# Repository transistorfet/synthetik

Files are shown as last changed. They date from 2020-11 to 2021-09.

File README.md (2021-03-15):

Synthetik
=========

###### *Started October 21, 2020*

This project started after I bought some old sound synthesis chips that were commonly used in
video game consoles and computers from the 80s and early 90s.  The first revision is a shield
for an Arduino Mega with 4 different chips: the General Instruments AY-3-8910 / Yamaha YM2149,
the YM2612 / YM3438 (OPN), the YM3812 (OPL2), and the YMF262 (OPL3).  It also has a MIDI in
port, line out stereo jack, and a headphone stereo jack with a TDA1308 power amplifier.

The board design had a large number of issues and mistakes, and I've so far only got it working
with one chip.

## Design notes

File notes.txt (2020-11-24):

Starting TTY Midi Bridge:

cd /media/work/Reference/Arduino/ttymidi
./ttymidi -s /dev/ttyACM2 -v

Connect VMPK to tty:

aconnect 130:0 128:1

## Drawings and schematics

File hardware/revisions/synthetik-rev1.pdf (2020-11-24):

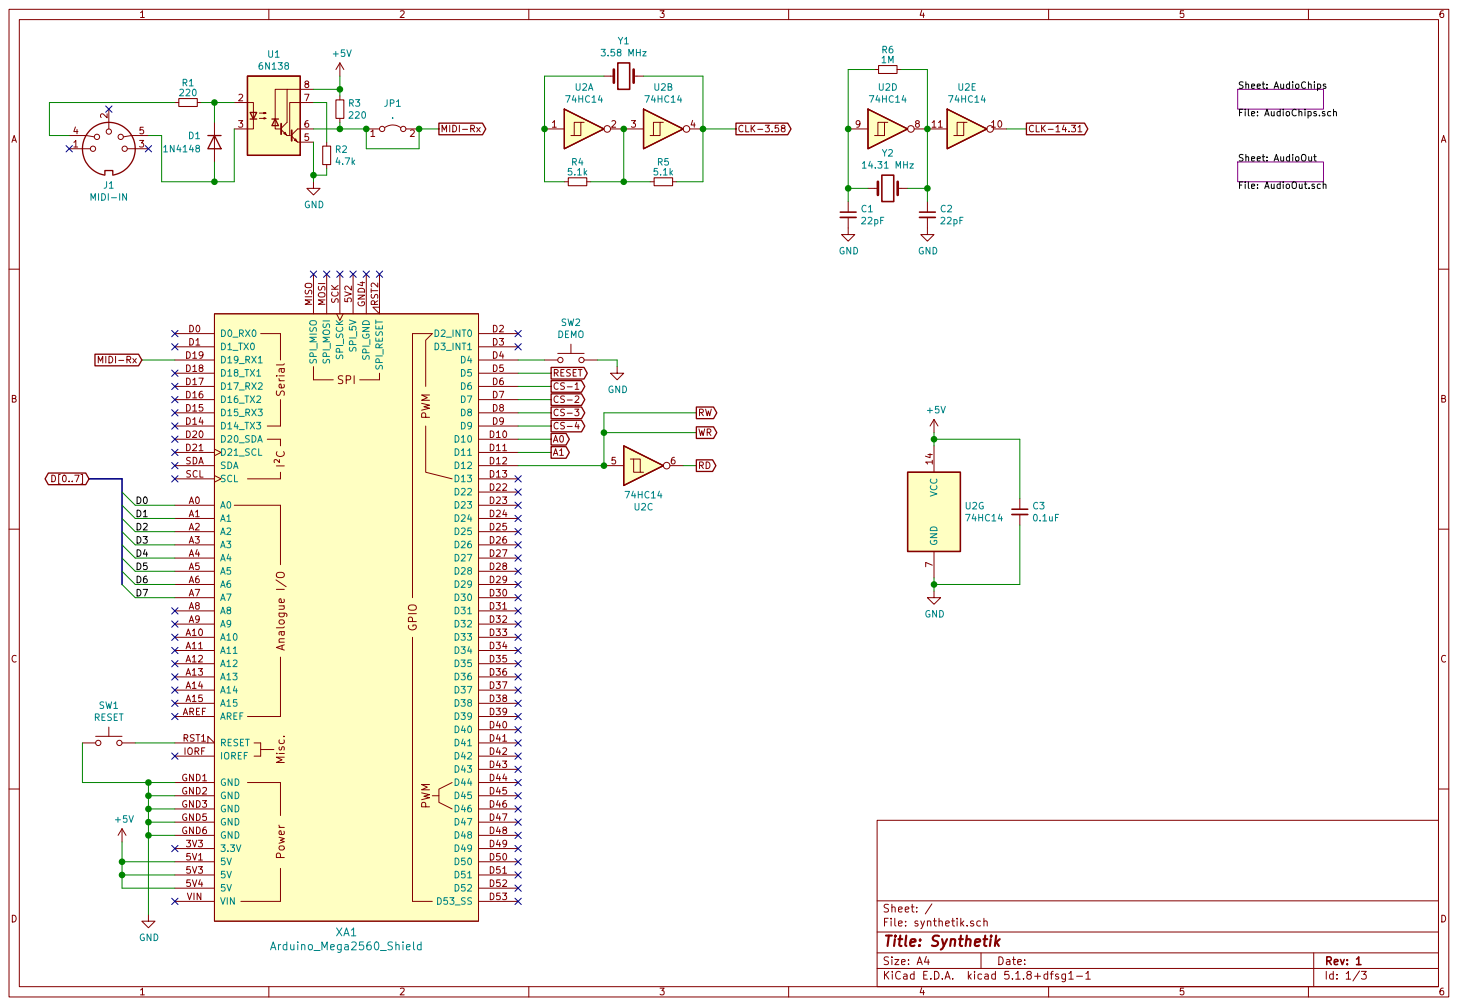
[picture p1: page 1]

Sheet: AudioOut File: AudioOut.sch Sheet: AudioChips

File: synthetik.sch Sheet: /
Id: 1/3 Title: Synthetik

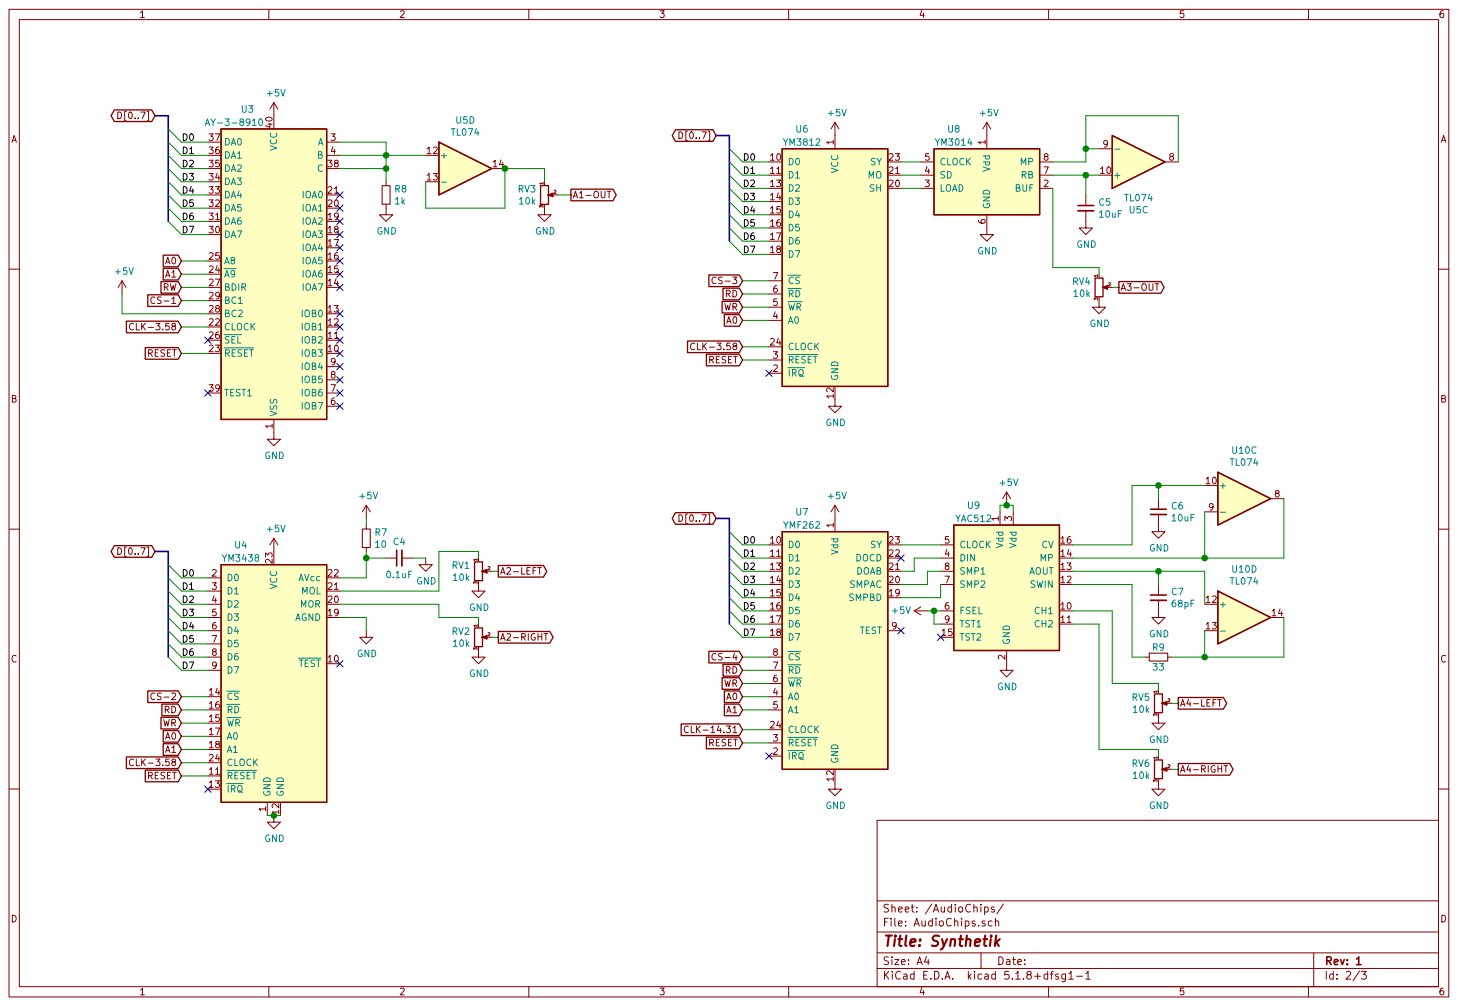
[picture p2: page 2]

A3-OUT D[0..7] CLK-3.58 RESET WR

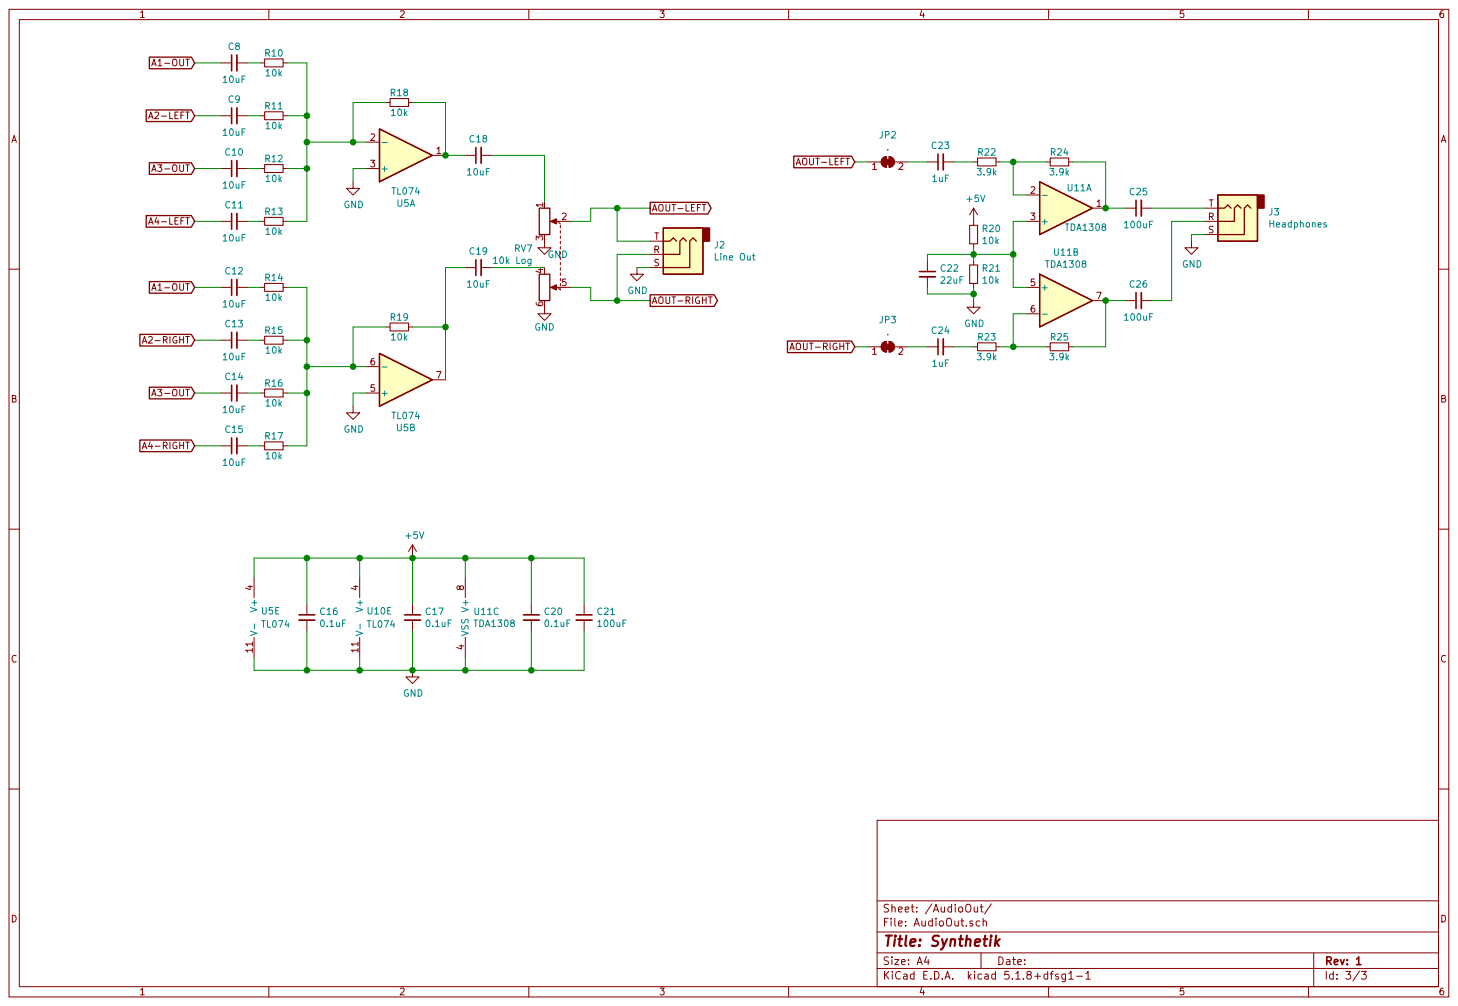
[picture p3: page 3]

File: AudioOut.sch Sheet: /AudioOut/
Id: 3/3 Title: Synthetik

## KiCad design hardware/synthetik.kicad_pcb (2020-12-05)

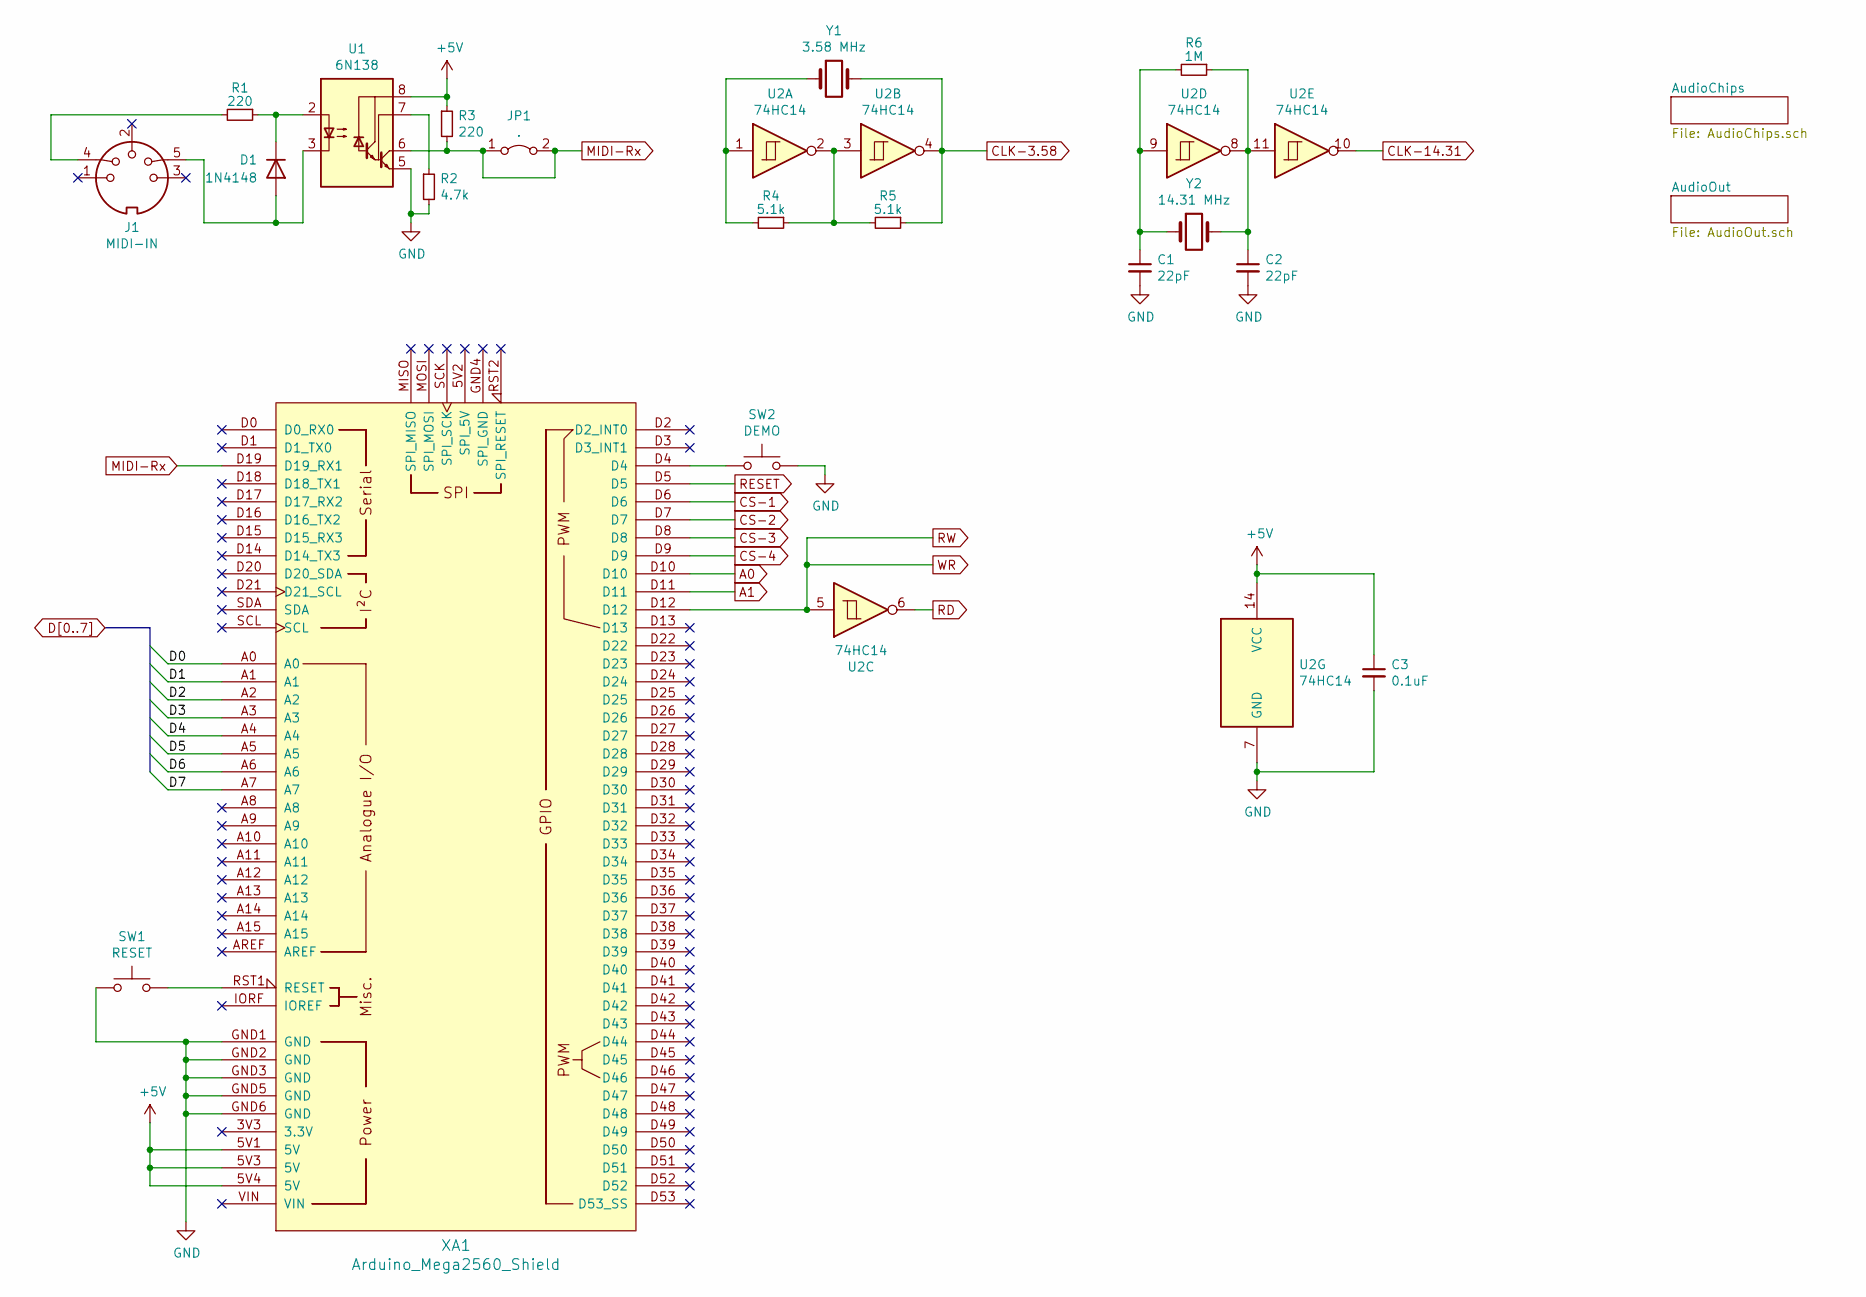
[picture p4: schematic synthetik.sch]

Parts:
C1, C2: 22pF; C_Disc_D3.0mm_W2.0mm_P2.50mm
C3: 0.1uF; C_Disc_D3.0mm_W2.0mm_P2.50mm
D1: 1N4148; D_DO-35_SOD27_P7.62mm_Horizontal
J1: MIDI-IN; MIDI_DIN5
JP1: .; PinHeader_1x02_P2.54mm_Vertical
R1, R3: 220; R_Axial_DIN0207_L6.3mm_D2.5mm_P7.62mm_Horizontal
R2: 4.7k; R_Axial_DIN0207_L6.3mm_D2.5mm_P7.62mm_Horizontal
R4, R5: 5.1k; R_Axial_DIN0207_L6.3mm_D2.5mm_P7.62mm_Horizontal
R6: 1M; R_Axial_DIN0207_L6.3mm_D2.5mm_P7.62mm_Horizontal
SW1: RESET; SW_PUSH_6mm
SW2: DEMO; SW_PUSH_6mm
U1: 6N138; DIP-8_W7.62mm_LongPads
U2: 74HC14; DIP-14_W7.62mm_Socket_LongPads
XA1: Arduino_Mega2560_Shield
Y1: 3.58 MHz; Crystal_HC49-4H_Vertical
Y2: 14.31 MHz; Crystal_HC49-4H_Vertical

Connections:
+5V: C3.1, R3.1, U1.8 (VCC), U2.14 (VCC), XA1.5V1 (5V), XA1.5V3 (5V), XA1.5V4 (5V); also elsewhere on the board
A0: XA1.D10; also elsewhere on the board
A1: XA1.D11; also elsewhere on the board
CLK-3.58: R5.1, U2.4, Y1.2; also elsewhere on the board
CLK-14.31: U2.10; also elsewhere on the board
CS-1: XA1.D6; also elsewhere on the board
CS-2: XA1.D7; also elsewhere on the board
CS-3: XA1.D8; also elsewhere on the board
CS-4: XA1.D9; also elsewhere on the board
D0: XA1.A0; also elsewhere on the board
D1: XA1.A1; also elsewhere on the board
D2: XA1.A2; also elsewhere on the board
D3: XA1.A3; also elsewhere on the board
D4: XA1.A4; also elsewhere on the board
D5: XA1.A5; also elsewhere on the board
D6: XA1.A6; also elsewhere on the board
D7: XA1.A7; also elsewhere on the board
GND: C1.2, C2.2, C3.2, R2.2, SW1.1, SW2.2, U1.5 (GND), U2.7 (GND), XA1.GND1 (GND), XA1.GND2 (GND), XA1.GND3 (GND), XA1.GND5 (GND), XA1.GND6 (GND); also elsewhere on the board
MIDI-Rx: JP1.1 (A), JP1.2 (B), R3.2, U1.6 (VO2), XA1.D19 (D19_RX1)
unnamed: C1.1, R6.2, U2.9, Y2.1
unnamed: C2.1, R6.1, U2.8, U2.11, Y2.2
unnamed: D1.1 (K), R1.1, U1.2 (C1)
unnamed: D1.2 (A), J1.5, U1.3 (C2)
unnamed: J1.4, R1.2
unnamed: R2.1, U1.7 (VO1)
unnamed: R4.1, R5.2, U2.2, U2.3
unnamed: R4.2, U2.1, Y1.1
unnamed: SW1.2, XA1.RST1 (RESET)
unnamed: SW2.1, XA1.D4
RD: U2.6; also elsewhere on the board
RESET: XA1.D5; also elsewhere on the board
RW: U2.5, XA1.D12; also elsewhere on the board

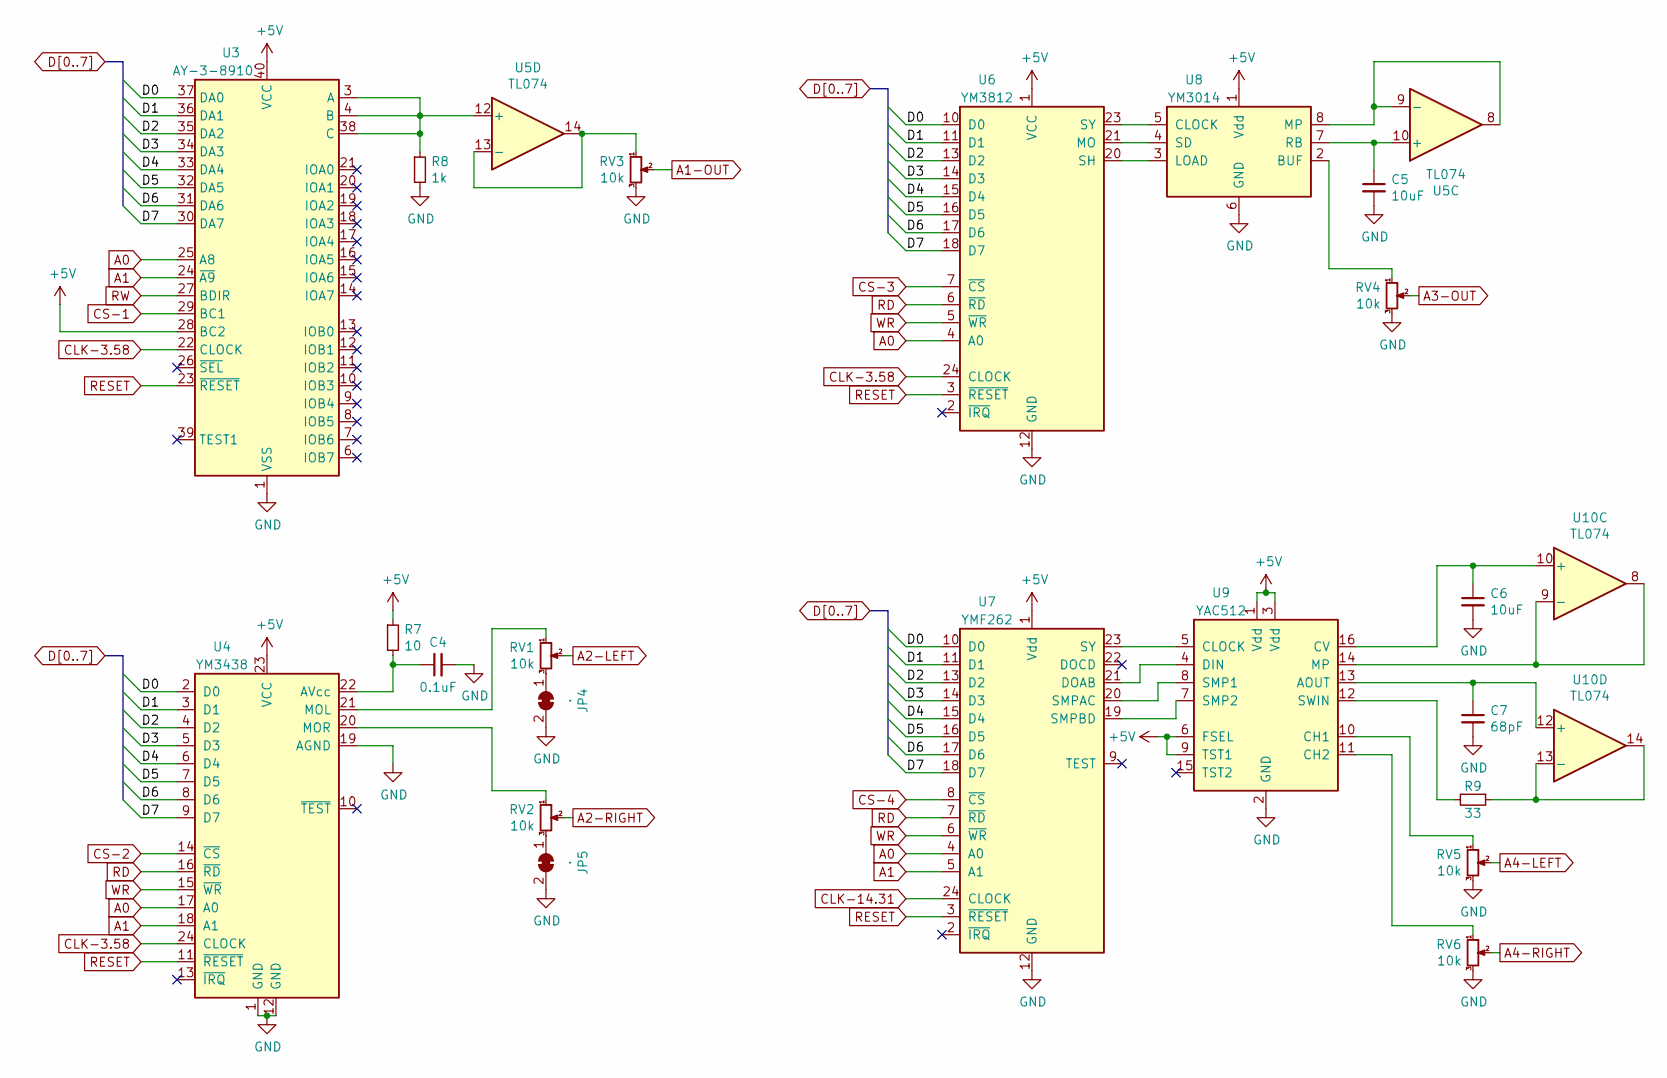
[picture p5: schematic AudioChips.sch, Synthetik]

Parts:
C4: 0.1uF; C_Disc_D3.0mm_W2.0mm_P2.50mm
C5, C6: 10uF; CP_Radial_D4.0mm_P1.50mm
C7: 68pF; C_Disc_D3.0mm_W2.0mm_P2.50mm
JP4, JP5: .; SolderJumper-2_P1.3mm_Bridged_RoundedPad1.0x1.5mm
R7: 10; R_Axial_DIN0207_L6.3mm_D2.5mm_P7.62mm_Horizontal
R8: 1k; R_Axial_DIN0207_L6.3mm_D2.5mm_P7.62mm_Horizontal
R9: 33; R_Axial_DIN0207_L6.3mm_D2.5mm_P7.62mm_Horizontal
RV1, RV2, RV3, RV4, RV5, RV6: 10k; Potentiometer_Bourns_3386P_Vertical
U3: AY-3-8910; DIP-40_W15.24mm_Socket_LongPads
U4: YM3438; DIP-24_W15.24mm_Socket_LongPads
U5: TL074; DIP-14_W7.62mm_Socket_LongPads
U6: YM3812; DIP-24_W15.24mm_Socket_LongPads
U7: YMF262; SOP-24_7.5x15.4mm_P1.27mm
U8: YM3014; DIP-8_W7.62mm_Socket_LongPads
U9: YAC512; SOP-16_4.55x10.3mm_P1.27mm
U10: TL074; SOIC-14_3.9x8.7mm_P1.27mm

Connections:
+5V: R7.1, U3.28 (BC2), U3.40 (VCC), U4.23 (VCC), U6.1 (VCC), U7.1 (Vdd), U8.1 (Vdd), U9.1 (Vdd), U9.3 (Vdd), U9.6 (FSEL), U9.9 (TST1); also elsewhere on the board
A0: U3.25 (A8), U4.17 (A0), U6.4 (A0), U7.4 (A0); also elsewhere on the board
A1: U3.24 (~A9), U4.18 (A1), U7.5 (A1); also elsewhere on the board
A1-OUT: RV3.2; also elsewhere on the board
A2-LEFT: RV1.2; also elsewhere on the board
A2-RIGHT: RV2.2; also elsewhere on the board
A3-OUT: RV4.2; also elsewhere on the board
A4-LEFT: RV5.2; also elsewhere on the board
A4-RIGHT: RV6.2; also elsewhere on the board
CLK-3.58: U3.22 (CLOCK), U4.24 (CLOCK), U6.24 (CLOCK); also elsewhere on the board
CLK-14.31: U7.24 (CLOCK); also elsewhere on the board
CS-1: U3.29 (BC1); also elsewhere on the board
CS-2: U4.14 (~CS); also elsewhere on the board
CS-3: U6.7 (~CS); also elsewhere on the board
CS-4: U7.8 (~CS); also elsewhere on the board
D0: U3.37 (DA0), U4.2 (D0), U6.10 (D0), U7.10 (D0); also elsewhere on the board
D1: U3.36 (DA1), U4.3 (D1), U6.11 (D1), U7.11 (D1); also elsewhere on the board
D2: U3.35 (DA2), U4.4 (D2), U6.13 (D2), U7.13 (D2); also elsewhere on the board
D3: U3.34 (DA3), U4.5 (D3), U6.14 (D3), U7.14 (D3); also elsewhere on the board
D4: U3.33 (DA4), U4.6 (D4), U6.15 (D4), U7.15 (D4); also elsewhere on the board
D5: U3.32 (DA5), U4.7 (D5), U6.16 (D5), U7.16 (D5); also elsewhere on the board
D6: U3.31 (DA6), U4.8 (D6), U6.17 (D6), U7.17 (D6); also elsewhere on the board
D7: U3.30 (DA7), U4.9 (D7), U6.18 (D7), U7.18 (D7); also elsewhere on the board
GND: C4.2, C5.2, C6.2, C7.2, JP4.2 (B), JP5.2 (B), R8.2, RV3.3, RV4.3, RV5.3, RV6.3, U3.1 (VSS), U4.1 (GND), U4.12 (GND), U4.19 (AGND), U6.12 (GND), U7.12 (GND), U8.6 (GND), U9.2 (GND); also elsewhere on the board
unnamed: C4.1, R7.2, U4.22 (AVcc)
unnamed: C5.1, U5.10 (+), U8.7 (RB)
unnamed: C6.1, U9.16 (CV), U10.10 (+)
unnamed: C7.1, U9.13 (AOUT), U10.12 (+)
unnamed: JP4.1 (A), RV1.3
unnamed: JP5.1 (A), RV2.3
unnamed: R8.1, U3.3 (A), U3.4 (B), U3.38 (C), U5.12 (+)
unnamed: R9.1, U10.13 (-), U10.14
unnamed: R9.2, U9.12 (SWIN)
unnamed: RV1.1, U4.21 (MOL)
unnamed: RV2.1, U4.20 (MOR)
unnamed: RV3.1, U5.13 (-), U5.14
unnamed: RV4.1, U8.2 (BUF)
unnamed: RV5.1, U9.10 (CH1)
unnamed: RV6.1, U9.11 (CH2)
unnamed: U5.8, U5.9 (-), U8.8 (MP)
unnamed: U6.20 (SH), U8.3 (LOAD)
unnamed: U6.21 (MO), U8.4 (SD)
unnamed: U6.23 (SY), U8.5 (CLOCK)
unnamed: U7.19 (SMPBD), U9.7 (SMP2)
unnamed: U7.20 (SMPAC), U9.8 (SMP1)
unnamed: U7.21 (DOAB), U9.4 (DIN)
unnamed: U7.23 (SY), U9.5 (CLOCK)
unnamed: U9.14 (MP), U10.8, U10.9 (-)
RD: U4.16 (~RD), U6.6 (~RD), U7.7 (~RD); also elsewhere on the board
RESET: U3.23 (~RESET), U4.11 (~RESET), U6.3 (~RESET), U7.3 (~RESET); also elsewhere on the board
RW: U3.27 (BDIR), U4.15 (~WR), U6.5 (~WR), U7.6 (~WR); also elsewhere on the board

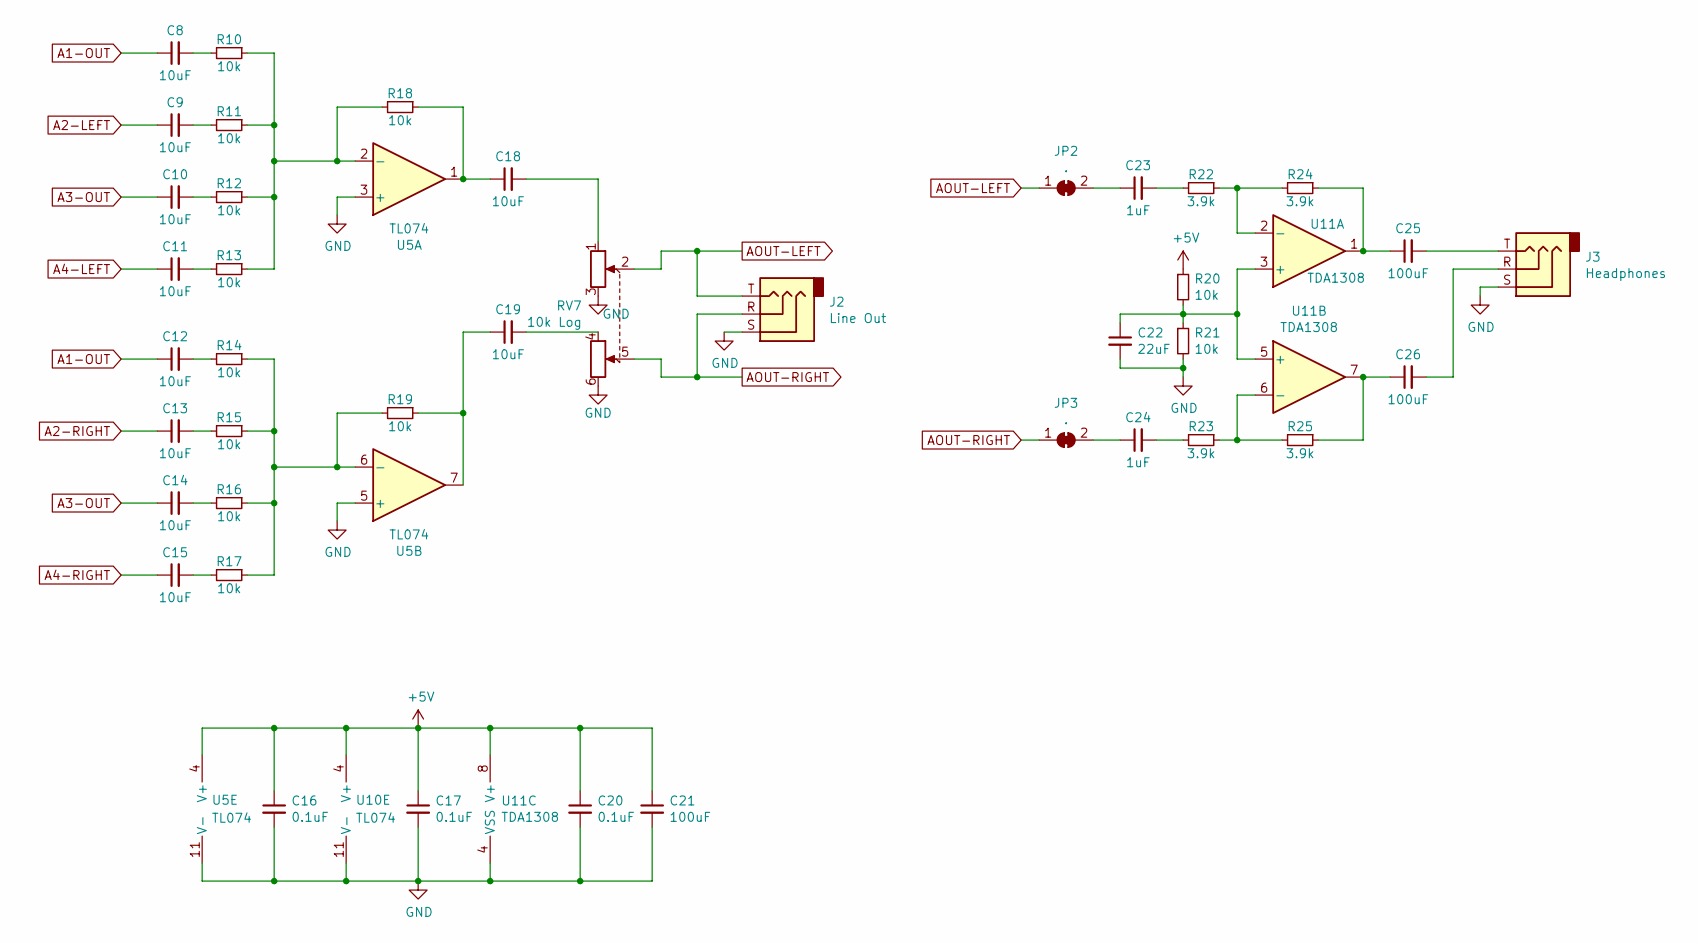
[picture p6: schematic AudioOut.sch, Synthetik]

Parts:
C8, C9, C10, C11, C12, C13, C14, C15, C18, C19: 10uF; CP_Radial_D4.0mm_P1.50mm
C16, C17, C20: 0.1uF; C_Disc_D3.0mm_W2.0mm_P2.50mm
C21, C25, C26: 100uF; CP_Radial_D6.3mm_P2.50mm
C22: 22uF; CP_Radial_D6.3mm_P2.50mm
C23, C24: 1uF; C_Disc_D3.0mm_W2.0mm_P2.50mm
J2: Line Out; Jack_3.5mm_CUI_SJ1-3533NG_Horizontal
J3: Headphones; Jack_3.5mm_CUI_SJ1-3533NG_Horizontal
JP2, JP3: .; SolderJumper-2_P1.3mm_Bridged_RoundedPad1.0x1.5mm
R10, R11, R12, R13, R14, R15, R16, R17, R18, R19, R20, R21: 10k; R_Axial_DIN0207_L6.3mm_D2.5mm_P7.62mm_Horizontal
R22, R23, R24, R25: 3.9k; R_Axial_DIN0207_L6.3mm_D2.5mm_P7.62mm_Horizontal
RV7: 10k Log; Potentiometer_Alpha_RD902F-40-00D_Dual_Vertical
U5: TL074; DIP-14_W7.62mm_Socket_LongPads
U10: TL074; SOIC-14_3.9x8.7mm_P1.27mm
U11: TDA1308; DIP-8_W7.62mm_Socket_LongPads

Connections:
+5V: C16.1, C17.1, C20.1, C21.1, R20.1, U5.4 (V+), U10.4 (V+), U11.8 (V+); also elsewhere on the board
A1-OUT: C8.1, C12.1; also elsewhere on the board
A2-LEFT: C9.1; also elsewhere on the board
A2-RIGHT: C13.1; also elsewhere on the board
A3-OUT: C10.1, C14.1; also elsewhere on the board
A4-LEFT: C11.1; also elsewhere on the board
A4-RIGHT: C15.1; also elsewhere on the board
AOUT-LEFT: J2.T, JP2.1 (A), RV7.2
AOUT-RIGHT: J2.R, JP3.1 (A), RV7.5
GND: C16.2, C17.2, C20.2, C21.2, C22.2, J2.S, J3.S, R21.2, RV7.3, RV7.6, U5.3 (+), U5.5 (+), U5.11 (V-), U10.11 (V-), U11.4 (VSS); also elsewhere on the board
unnamed: C8.2, R10.2
unnamed: C9.2, R11.2
unnamed: C10.2, R12.2
unnamed: C11.2, R13.2
unnamed: C12.2, R14.2
unnamed: C13.2, R15.2
unnamed: C14.2, R16.2
unnamed: C15.2, R17.2
unnamed: C18.1, R18.1, U5.1
unnamed: C18.2, RV7.1
unnamed: C19.1, R19.1, U5.7
unnamed: C19.2, RV7.4
unnamed: C22.1, R20.2, R21.1, U11.3 (+), U11.5 (+)
unnamed: C23.1, JP2.2 (B)
unnamed: C23.2, R22.2
unnamed: C24.1, JP3.2 (B)
unnamed: C24.2, R23.2
unnamed: C25.1, R24.1, U11.1
unnamed: C25.2, J3.T
unnamed: C26.1, R25.1, U11.7
unnamed: C26.2, J3.R
unnamed: R10.1, R11.1, R12.1, R13.1, R18.2, U5.2 (-)
unnamed: R14.1, R15.1, R16.1, R17.1, R19.2, U5.6 (-)
unnamed: R22.1, R24.2, U11.2 (-)
unnamed: R23.1, R25.2, U11.6 (-)

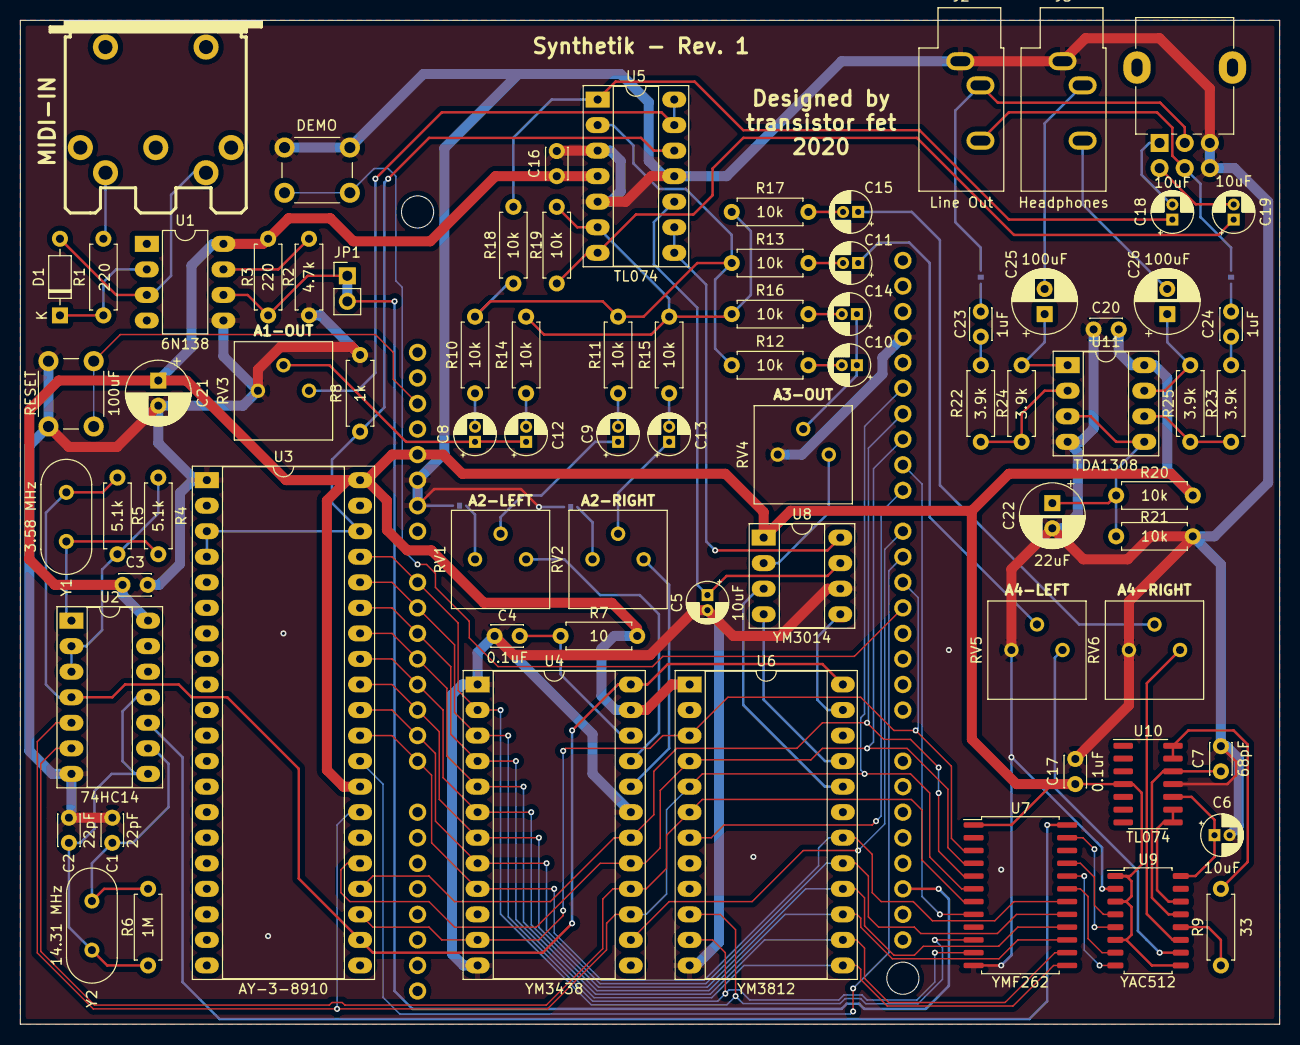
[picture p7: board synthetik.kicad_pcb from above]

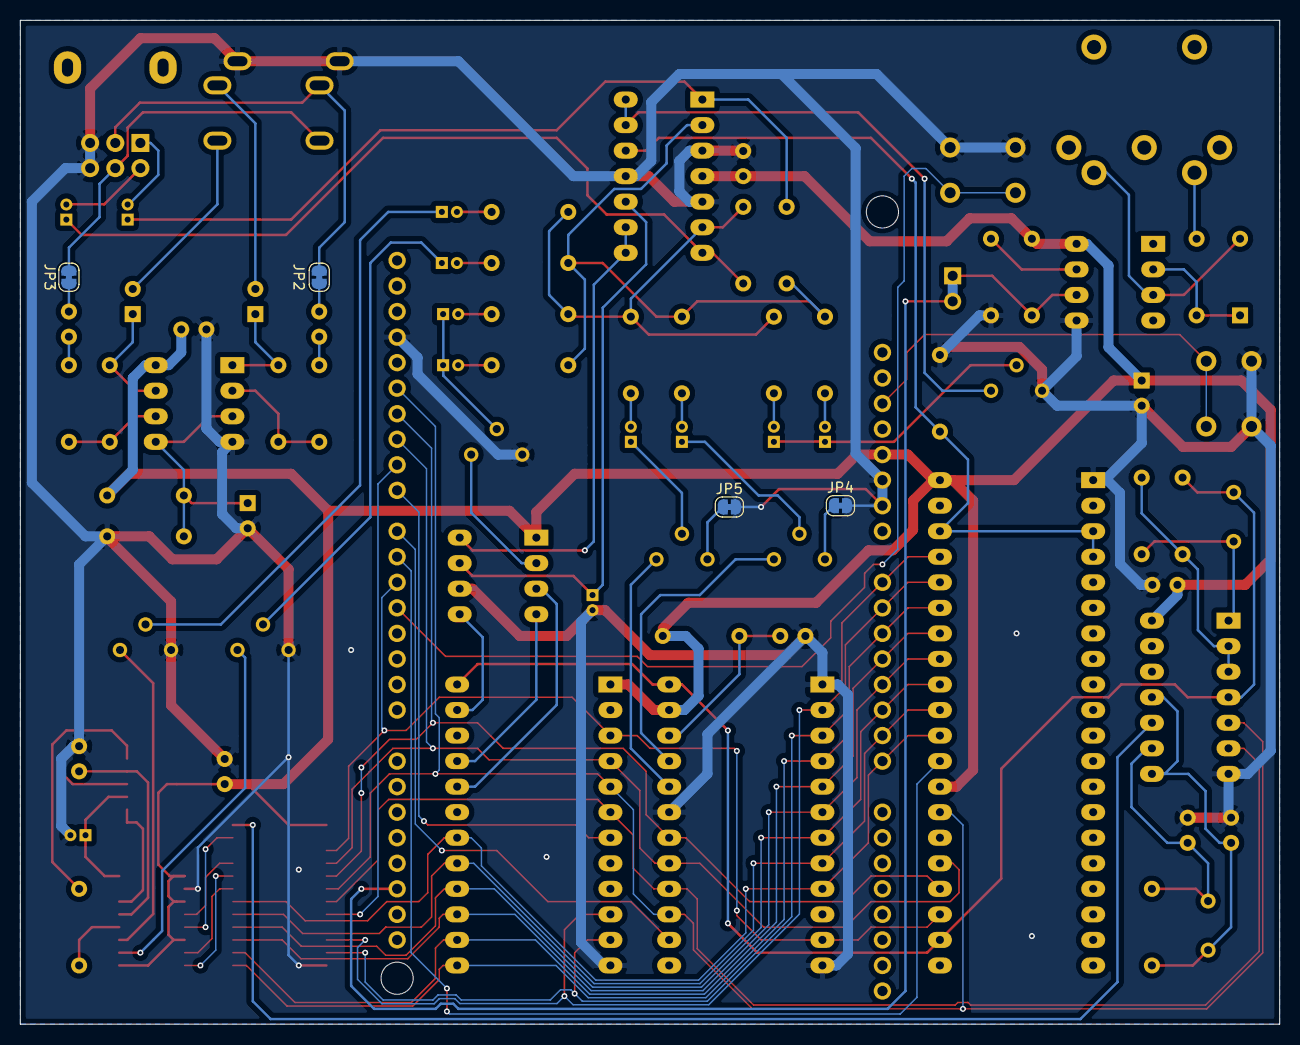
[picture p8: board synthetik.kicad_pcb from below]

Board: 2 copper layers, 125.2 x 99.8 mm, 83 parts (4 on the bottom side), 89 nets.

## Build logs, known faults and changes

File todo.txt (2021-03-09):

* replace YM3438 resistors with 1k or 2.2k, and the Rf resistors of the op amp with 5.1k.  The amplification should be 5.1k/1k at the high end and 5.1k/11k at the low end of the trim pot
* maybe remove the YM3812 trim pot so we can rewire it with a fixed volume at a later date.  Should I maybe put in 1k/2.2k resistors for that chip as well???

* should you move the audio pot to only control the power amp volume and not the line in volume?

* can I add some helpful things to avoid desoldering?
	* ability to bypass the onboard amps?
	* ability to easily swap out resistor values for amp gain

PLANNING:

* should you use an uno or a mega?  It might be good to have more ram for the instruments??
* later revision could have an integrated arduino or STM32
* should you add another type of output, like RCA?
* should you add jumpers or switches to turn on/off certain channels?

* I'm thinking 4 chips is sufficient, AY, OPNx, OPLx, and maybe OPM
* need to buy more YM2151, YM2413, and maybe YM2164 and YMF278?

* chips that could be used
	AY-3-8910/YM2149
	YM2612/YM3438 (OPN2/OPN2C, might need different audio output resistors to work for either)
	YM3812 (OPL2)
	YMF262 (OPL3)
	YMF278 (OPL4?? I don't think I have one)
	YMF288 (OPN3)
	YM2151 (OPM)
	YM2164 (OPP)
	YM2413 (OPLL, maybe overkill)
	SN76496 (but I couldn't get it working on the breadboard)
	YM2608/YM2610

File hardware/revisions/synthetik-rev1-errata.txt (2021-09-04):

 
Revision 1 Errata and Notes
===========================

- the mixer is wired quite incorrectly.  The non-inverting inputs are tied to ground when they should be tied to a 2.5V reference.
  As a result, there is no sound.  Added two 10k resistors and a 10uF capacitor with a jumper wire to the exposed pins to fix it

- the trim potentiometers are mounted upside down for what they should be

- the volume potentiometer is too far back on the board.  The actual part number I ordered doesn't have the anchor pins

- the mixer doesn't work properly.  With only the YM3438 connected, and the mixer resistors replaced with 2.2k, and the op amp
  feedback resistors changed to 4.7k, that one chip is producing sound.  I also removed the YM3812 trim pot and cut the trace
  between the mixer inputs to isolate it so it didn't interfere

- there is a humming and I haven't figured out what's causing it yet

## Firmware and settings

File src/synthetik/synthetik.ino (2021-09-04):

#include "NerveSerial.h"
#include "YM3812.h"
#include "YM3438.h"
#include "AY3.h"

#include <MIDI.h>


#define SERIAL_SPEED	115200

/*
NerveSerial nSerial(&Serial);

void command_write()
{
	byte addr;
	byte value;

	addr = strtol(nSerial.get_arg(0), NULL, 0);
	value = strtol(nSerial.get_arg(1), NULL, 0);

	opl_write_data(addr, value);
}

void command_reset()
{
	Serial.print("error\n");
}

void command_default()
{
	Serial.print("error\n");
}

NerveCommand_t command_list[] = {
	{ "write", 2, command_write },
	{ "reset", 0, command_reset },
	{ 0, 0, command_default }
};

void nerve_init()
{
	Serial.begin(SERIAL_SPEED);
	nSerial.set_commands(command_list);
}
*/

MIDI_CREATE_DEFAULT_INSTANCE();
//MIDI_CREATE_INSTANCE(HardwareSerial, Serial1, MIDI);


void handleNoteOn(byte channel, byte note, byte velocity)
{
	if (channel == 10) {
		opl_drum_on(note);
	}
	else {
		if (velocity)
			opl_note_on(channel - 1, note);
		else
			opl_note_off(channel - 1, note);
	}
}

void handleNoteOff(byte channel, byte note, byte velocity)
{
	if (channel == 10) {
		opl_drum_off(note);
	}
	else {
		opl_note_off(channel - 1, note);
	}
}

void handleProgramChange(byte channel, byte number)
{
	opl_change_instrument(channel - 1, number);
}

void handleControlChange(byte channel, byte number, byte value)
{
	opl_change_parameter(channel - 1, number, value);
}

void debug_midi(byte channel, byte data)
{
	MIDI.sendProgramChange(data, channel + 1);
}

void midi_init()
{
	MIDI.begin(MIDI_CHANNEL_OMNI);
	MIDI.setHandleNoteOn(handleNoteOn);
    	MIDI.setHandleNoteOff(handleNoteOff);
    	MIDI.setHandleProgramChange(handleProgramChange);
    	MIDI.setHandleControlChange(handleControlChange);
	Serial.begin(SERIAL_SPEED);
}

void setup()
{
	pinMode(13, OUTPUT);
	digitalWrite(13, 0);

	opl_setup_audio();
	opl_init_audio();

	//opn_setup();
	//opn_init_audio();

	//ay3_init_audio();
	//ay3_run_test();

	//nerve_init();
	midi_init();
}

void loop()
{
	//nSerial.check_read();

	MIDI.read();
}


/*
#define SERIAL_SIZE	64

char serial_read_tail = 0;
char serial_read_head = 0;
char serial_avail = 0;
char serial_rb[SERIAL_SIZE];
char serial_write_head = 0;
char serial_write_tail = 0;
char serial_wb[SERIAL_SIZE];

byte read_serial()
{
	register char b;

	b = Serial.read();
	if (b == -1)
		return 0;

	noInterrupts();
	serial_rb[serial_read_tail] = b;
	if (b == '\n' || b == '\r') {
		serial_rb[serial_read_tail] = '\0';
		serial_avail = 1;
	}
	if (serial_read_tail < SERIAL_SIZE)
		serial_read_tail++;
	interrupts();
	return serial_avail;
}

inline byte serial_get_byte()
{
	register byte value;

	noInterrupts();
	if (serial_read_head == serial_read_tail) {
		//clear_read_buffer();
		value = -1;
	} else {
		value = serial_rb[serial_read_head++];
		if (serial_read_head >= SERIAL_SIZE)
			serial_read_head = 0;
	}
	interrupts();
	return value;
}

inline byte serial_add_byte(byte data)
{
	noInterrupts();
	serial_wb[serial_write_tail++] = data;
	interrupts();
}

void clear_read_buffer()
{
	noInterrupts();
	serial_avail = 0;
	serial_read_head = 0;
	serial_read_tail = 0;
	interrupts();
}

void flush_write_buffer()
{
	if (serial_write_tail > 0) {
		noInterrupts();
		for (byte i = 0; i < serial_write_tail; i++) {
			Serial.write(serial_wb[i]);
		}
		serial_write_head = 0;
		serial_write_tail = 0;
		interrupts();
	}
}



void do_command(String line)
{
	if (line.equals("mute")) {
		opn_mute();
	}
	else if (line.equals("unmute")) {
		opn_unmute();
	}
	else if (line.equals("reset")) {
		opn_reset();
	}
	else {
		Serial.println("No such command");
	}
}

void setup()
{
	Serial.begin(SERIAL_SPEED);

	pinMode(13, OUTPUT);
	digitalWrite(13, 0);

	opn_setup();

	opn_init_audio();

	Serial.print("> ");
}

void loop()
{
	//String line = Serial.readString();
	//do_command(line);

	//flush_write_buffer();

	if (read_serial()) {
		String line = String(serial_rb);
		clear_read_buffer();
		Serial.print(line);
		Serial.print("\n");
		do_command(line);
		Serial.print("\n> ");
	}
}


*/

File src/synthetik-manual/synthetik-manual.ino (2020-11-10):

#include "NerveSerial.h"
#include "YM3812.h"

#include <MIDI.h>


/******************************
 * Serial Communications Code *
 ******************************/

#define SERIAL_SPEED	115200

NerveSerial nSerial(&Serial);
//MIDI_CREATE_DEFAULT_INSTANCE();


/**********************
 * Audio Control Code *
 **********************/

void set_tone(byte channel, word tone)
{
	ym_write_data(0 + (channel * 2), tone & 0xff);
	ym_write_data(1 + (channel * 2), (tone >> 8) & 0xff);
}

#define CLOCK	3686400

#define NOTE_C3		(CLOCK / (16 * 130.81))
#define NOTE_D3		(CLOCK / (16 * 146.83))
#define NOTE_E3		(CLOCK / (16 * 164.81))
#define NOTE_F3		(CLOCK / (16 * 174.61))
#define NOTE_G3		(CLOCK / (16 * 196.00))
#define NOTE_A3		(CLOCK / (16 * 220.00))
#define NOTE_B3		(CLOCK / (16 * 246.94))
#define NOTE_C4		(CLOCK / (16 * 261.63))
#define NOTE_D4		(CLOCK / (16 * 293.66))
#define NOTE_E4		(CLOCK / (16 * 329.63))
#define NOTE_F4		(CLOCK / (16 * 349.23))
#define NOTE_G4		(CLOCK / (16 * 392.00))

void run_reset()
{
	initialize_audio();
}

void play_note(byte note, word length)
{
	ym_write_data(0xA0, note);
	ym_write_data(0xB0, 0x31);		// Turn the voice on; set the octave and freq MSB
	delay(length);
	ym_write_data(0xB0, 0x11);		// Turn the voice off; set the octave and freq MSB
	delay(100);
}

void run_test()
{

	play_note(0x98, 800);
	play_note(0xA0, 800);
	play_note(0xB0, 800);
	play_note(0x85, 800);
	play_note(0x98, 800);

/*
	ym_write_data(13, 0xFF);
	ym_write_data(14, 0xFF);
	ym_write_data(15, 0x00);

	set_tone(0, NOTE_E4);
	delay(200);
	set_tone(0, 0);
	delay(20);

	set_tone(0, NOTE_E4);
	delay(150);
	set_tone(0, 0);
	delay(20);

	set_tone(0, NOTE_E4);
	delay(150);
	set_tone(0, 0);
	delay(20);

	delay(100);

	set_tone(0, NOTE_C4);
	delay(100);
	set_tone(0, 0);
	delay(20);

	set_tone(0, NOTE_E4);
	delay(100);
	set_tone(0, 0);
	delay(20);

	delay(200);

	set_tone(0, NOTE_G4);
	delay(200);
	set_tone(0, 0);
	delay(20);

	delay(200);

	set_tone(0, NOTE_G3);
	delay(200);
	set_tone(0, 0);
	delay(20);
*/
}

void command_write()
{
	byte addr;
	byte value;

	addr = strtol(nSerial.get_arg(0), NULL, 0);
	value = strtol(nSerial.get_arg(1), NULL, 0);

	ym_write_data(addr, value);
}

void command_default()
{
	Serial.print("error\n");
}

NerveCommand_t command_list[] = {
	{ "write", 2, command_write },
	{ 0, 0, command_default }
};

/*
void do_command(String line)
{
	if (line.equals("test")) {
		run_test();
	}
	else if (line.startsWith("write ")) {
		run_write(line);
	}
	else if (line.equals("reset")) {
		run_reset();
	}
	else {
		Serial.println("No such command");
	}
}
*/

void handleNoteOn(byte inChannel, byte inNote, byte inVelocity)
{
	word upper = (inNote >> 5);
	ym_write_data(0xA0, inNote << 3);
	ym_write_data(0xB0, 0x30 | upper);
}

void handleNoteOff(byte inChannel, byte inNote, byte inVelocity)
{
	ym_write_data(0xB0, 0x10);
}

void setup()
{
	setup_audio();
	initialize_audio();

	/*
	MIDI.begin(MIDI_CHANNEL_OMNI);
	MIDI.setHandleNoteOn(handleNoteOn);
    	MIDI.setHandleNoteOff(handleNoteOff);
	Serial.begin(SERIAL_SPEED);
	*/

	Serial.begin(SERIAL_SPEED);
	nSerial.set_commands(command_list);

	pinMode(13, OUTPUT);
	digitalWrite(13, 0);


	//Serial.print("> ");
}

void loop()
{
	//String line = Serial.readString();
	//do_command(line);

	//flush_write_buffer();

	/*
	if (read_serial()) {
		String line = String(serial_rb);
		clear_read_buffer();
		Serial.print(line);
		Serial.print("\n");
		do_command(line);
		Serial.print("\n> ");
	}
	*/

	nSerial.check_read();

	//MIDI.read();
}

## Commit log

2020-11-24 Added PCB design
    [AudioChips.sch, AudioOut.sch, synthetik.kicad_pcb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]
2020-12-05 Final rev.1 PCB design
    [AudioChips.sch, synthetik.kicad_pcb]
